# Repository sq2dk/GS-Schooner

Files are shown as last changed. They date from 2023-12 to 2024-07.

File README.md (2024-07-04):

# GS-Schooner
SP2ZIE Schooner Ground Station

This is repository for Ground Station for PWSat-3 satellite.

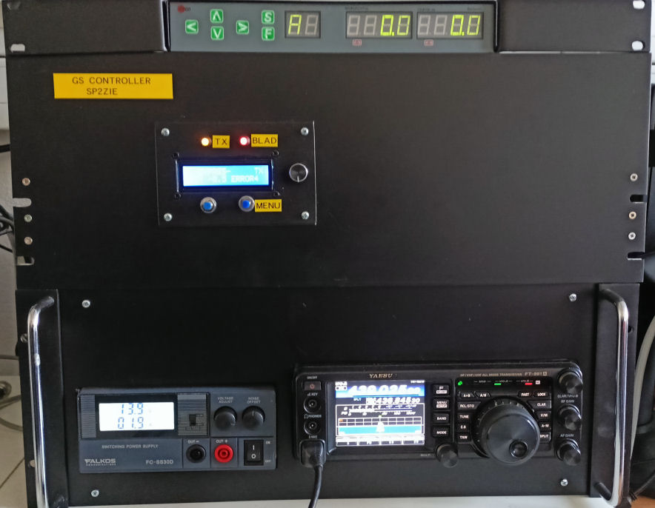
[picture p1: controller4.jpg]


## Overview

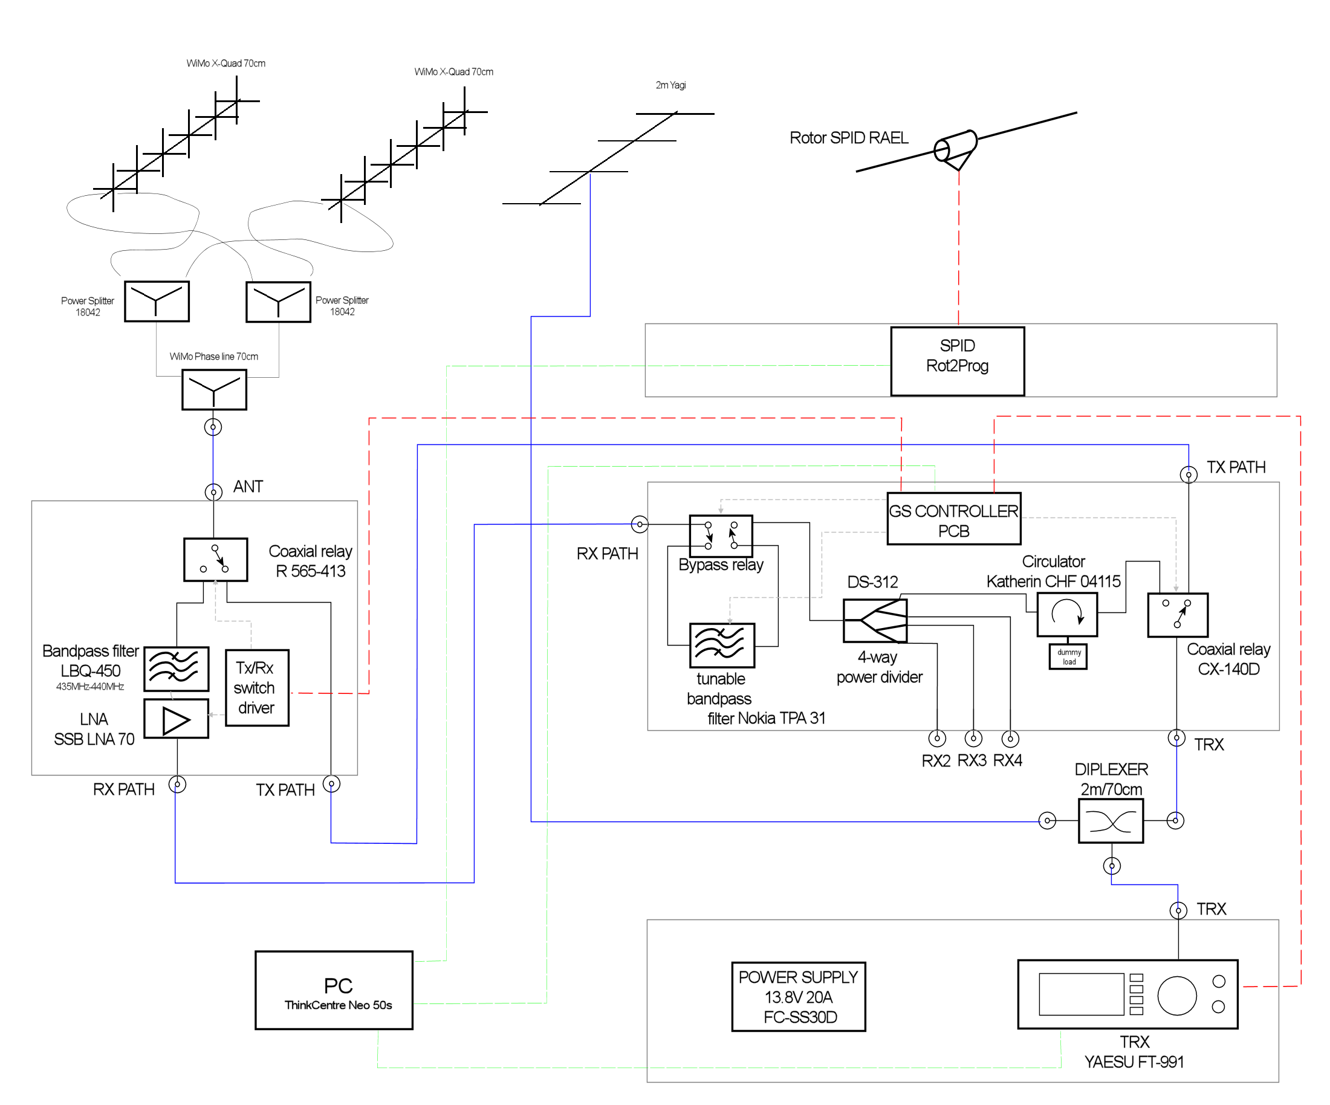
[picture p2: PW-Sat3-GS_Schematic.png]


Future PWSat-3 satellite will have communication module based on simplex operation on 437.xxxMHz. Modulation used would be most likely 2GFSK with downlink speeds from 1200bd up to maximum possible speeds which assure correct decoding. Uplink speeds will be probably limited to max 9600bd. Satellite will be using Endurosat UHF Transceiver II module, which seem to be based on one of the popular sub-gigahertz communications IC such as SI4463 or similar.

Simplex operation means that the same frequency will be used for uplink and transmit. This poses additional challenge of switching between transmitting and receiving, as the same antenna will be used both for transmit and receive side. Additionally to ensure effective communication with satellite, high transmit power should be used, and since satellite itself uses low power transmitter, ground station receiver has to be able to receive low signals. 

To help with weak signal receiving and maximizing power radiating by transmitter directional antennas have to be used. We have decided to use system of two shorter directional antennas rather, than one long antenna, as they are more manageable mechanicaly. Due to the undetermined orientation of satellite in space antennas have to have circular polarisation to avoid signal fade-outs.

Since antennas are directional, they need to be painted to satellite at all times – antenna rotator able to change position in azimuth and elevation is required.

To compensate for coaxial cable loss low noise amplifier for received signals is used placed next to the antenna. 

Due to high radio noise environment and presence of nearby high power transmitters on frequencies lying close to frequency of interest RF bandpass filter is added before LNA, not to saturate amplifier with unwanted signal.

Additional very low passband (about 100kHz) filter can be connected in line to further limit noise from unwanted transmissions. This filter due to low bandpass characteristic is tunable by stepper motor to tune to required frequency.

Received signal is further divided to 4 paths to allow simultaneous operation of up to 4 receivers (main station and up to 3 SDR receivers). Those might be essential to decode transmissions with speed of above 9600bd. 

TX path of the station leads directly from transmitter to antennas via 2 relays.

Yaesu FT-991 wash chosen as main transceiver. Although this radio is not specifically designed for satellite use, transceiver was only one currently in production and available on the market capable of producing 50W of RF power on 70cm band with 9600bd transmission/rx capability. 

## GS controller

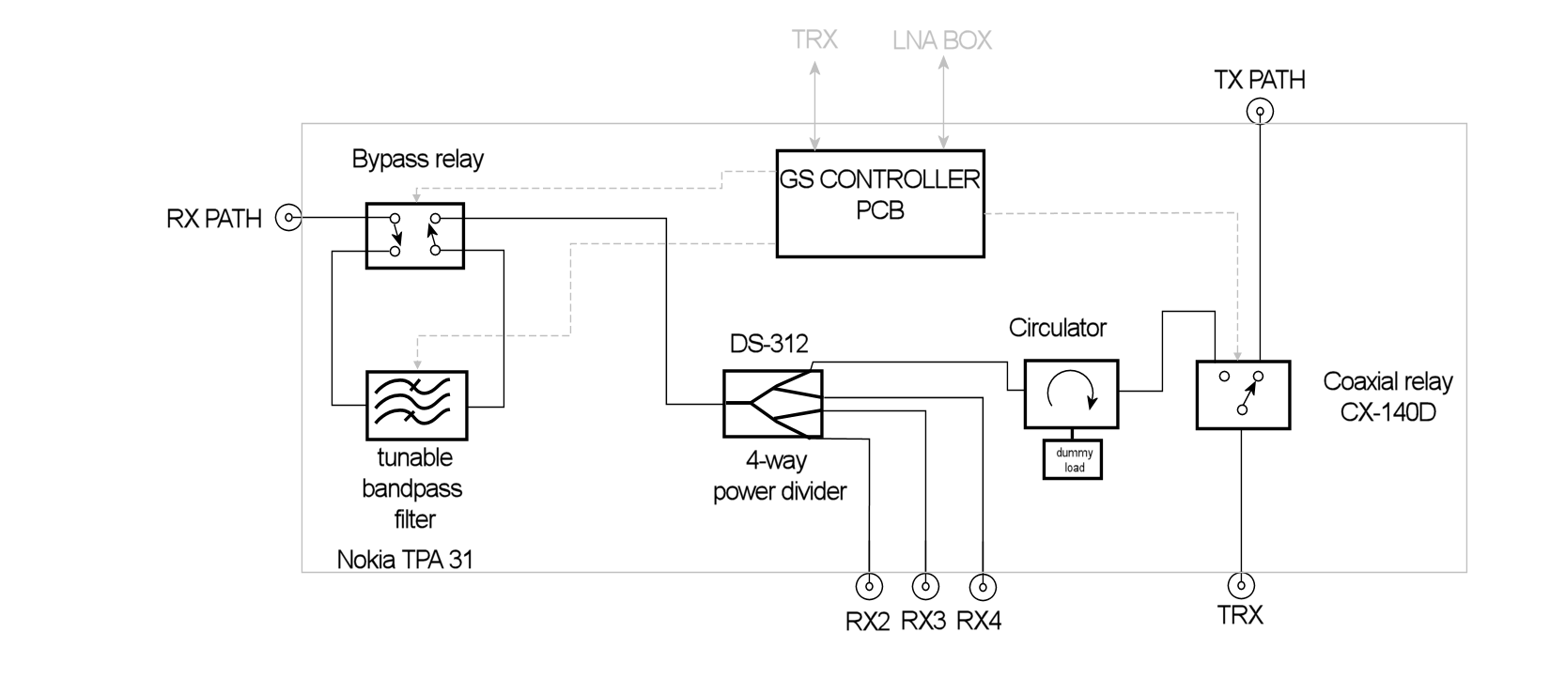
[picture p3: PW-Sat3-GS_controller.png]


Primary role of GS controller is managing switching between transmit and receive modes. Additionally block is additionally filtering and distributing signal for the receivers. All functions can be controlled by computer by serial protocol or manually by keys and encoders. On request from transmitter controller is checking if all conditions for transmit switching are meet and only then sends signal back to TRX to allow transmitting. Control and switching function as well as human interface functions are made by specially designed PCB based on STM blue pill microcontroller. Schematic of electronic circuit and PCB designed can be found in appropriate folder.  
Embedded software is written in Arduino environment and it is available in appropriate folder. 

## LNA Box
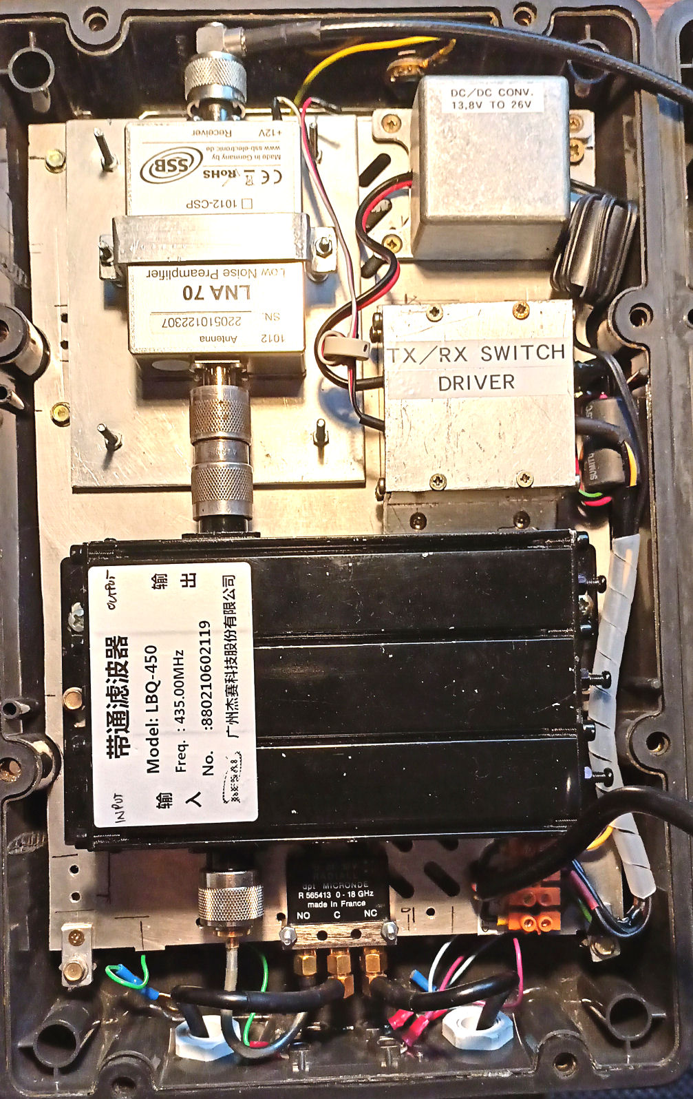
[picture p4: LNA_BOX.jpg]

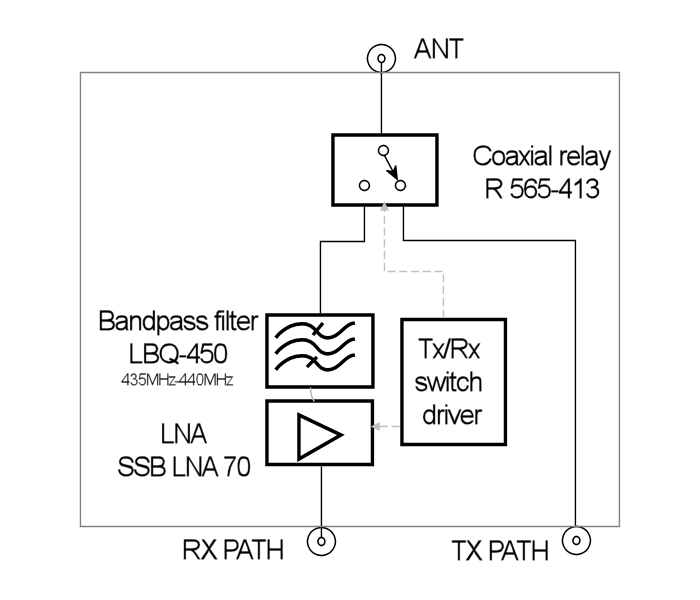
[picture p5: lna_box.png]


This part contains LNA, RF bandpass filter, RF relay and electronic driver for relay and LNA power supply. Schematic and PCB design for driver is included in appropriate folder. This is a simple transistor and relay switch. 4 wire interface to GS controlled is used. 12V power, ground, RX signal (to GND) and feedback signal are passed from/to GS controller. Separate TX and RX lines are feed from GS controller to LNA box. Although this solution requires extra coaxial cable, it simplifies design a bit, since other coaxial relay for TX/RX switching can be placed in below deck equipment (BDE).  
## Antenna system

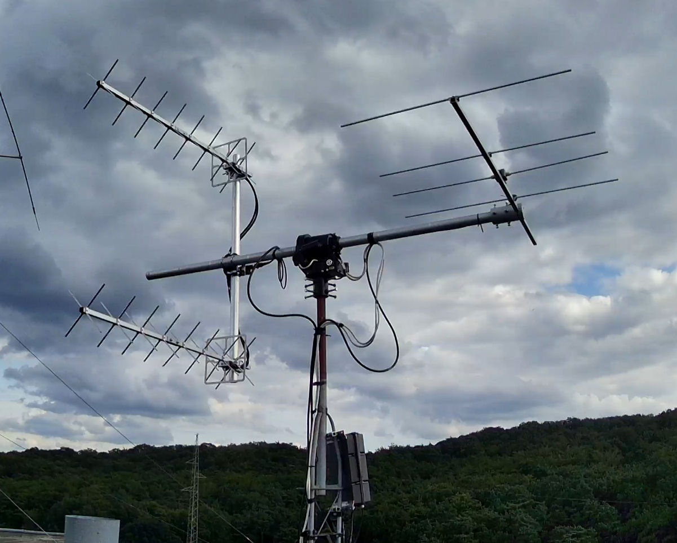
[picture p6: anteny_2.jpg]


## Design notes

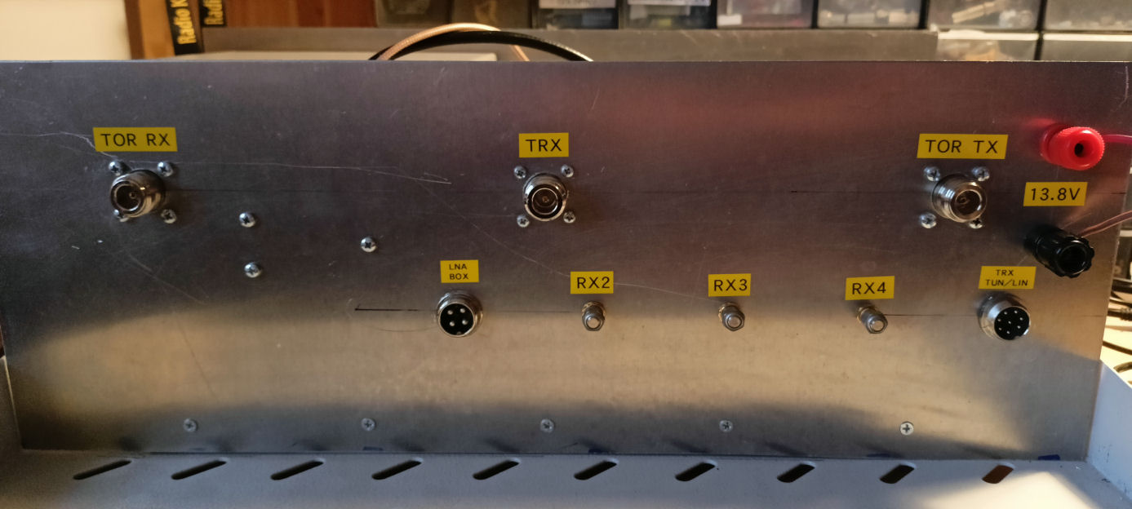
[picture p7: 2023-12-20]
controller1.jpg

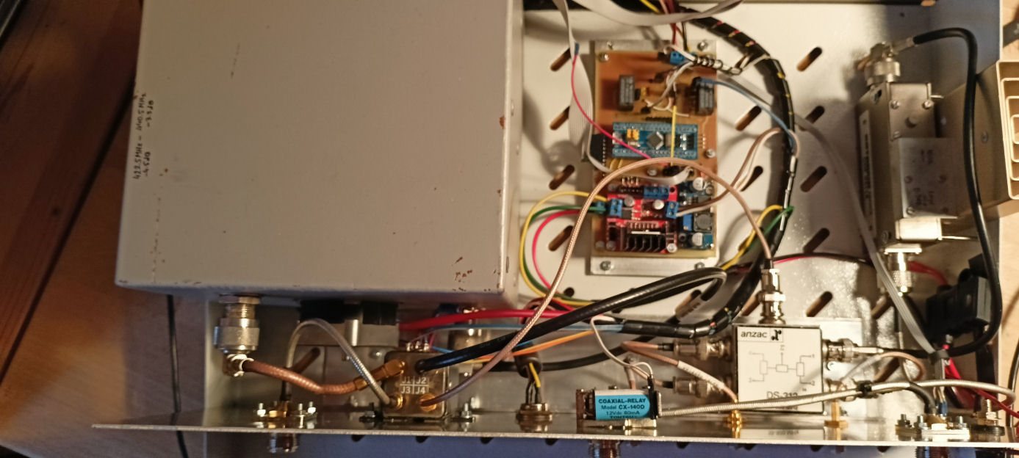
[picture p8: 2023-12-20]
controller2.jpg

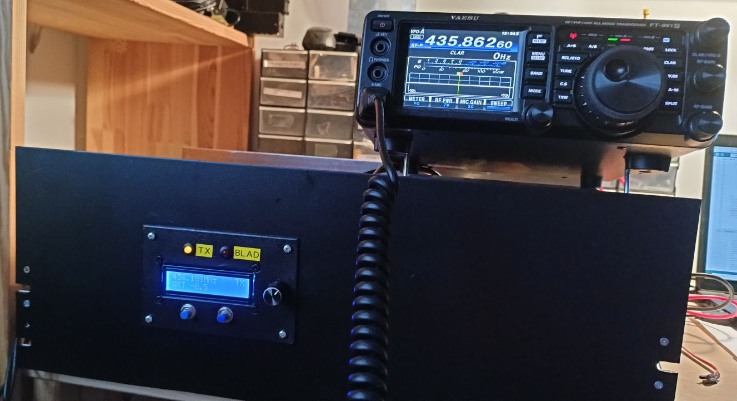
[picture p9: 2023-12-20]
controller3.jpg

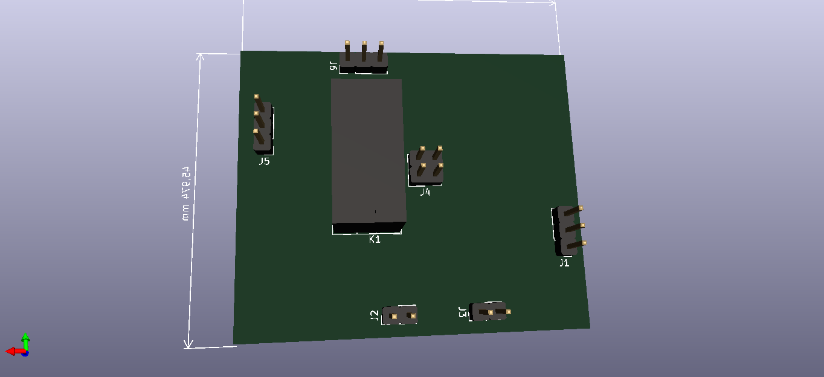
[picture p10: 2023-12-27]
lna_switch/lna_switch_2.png

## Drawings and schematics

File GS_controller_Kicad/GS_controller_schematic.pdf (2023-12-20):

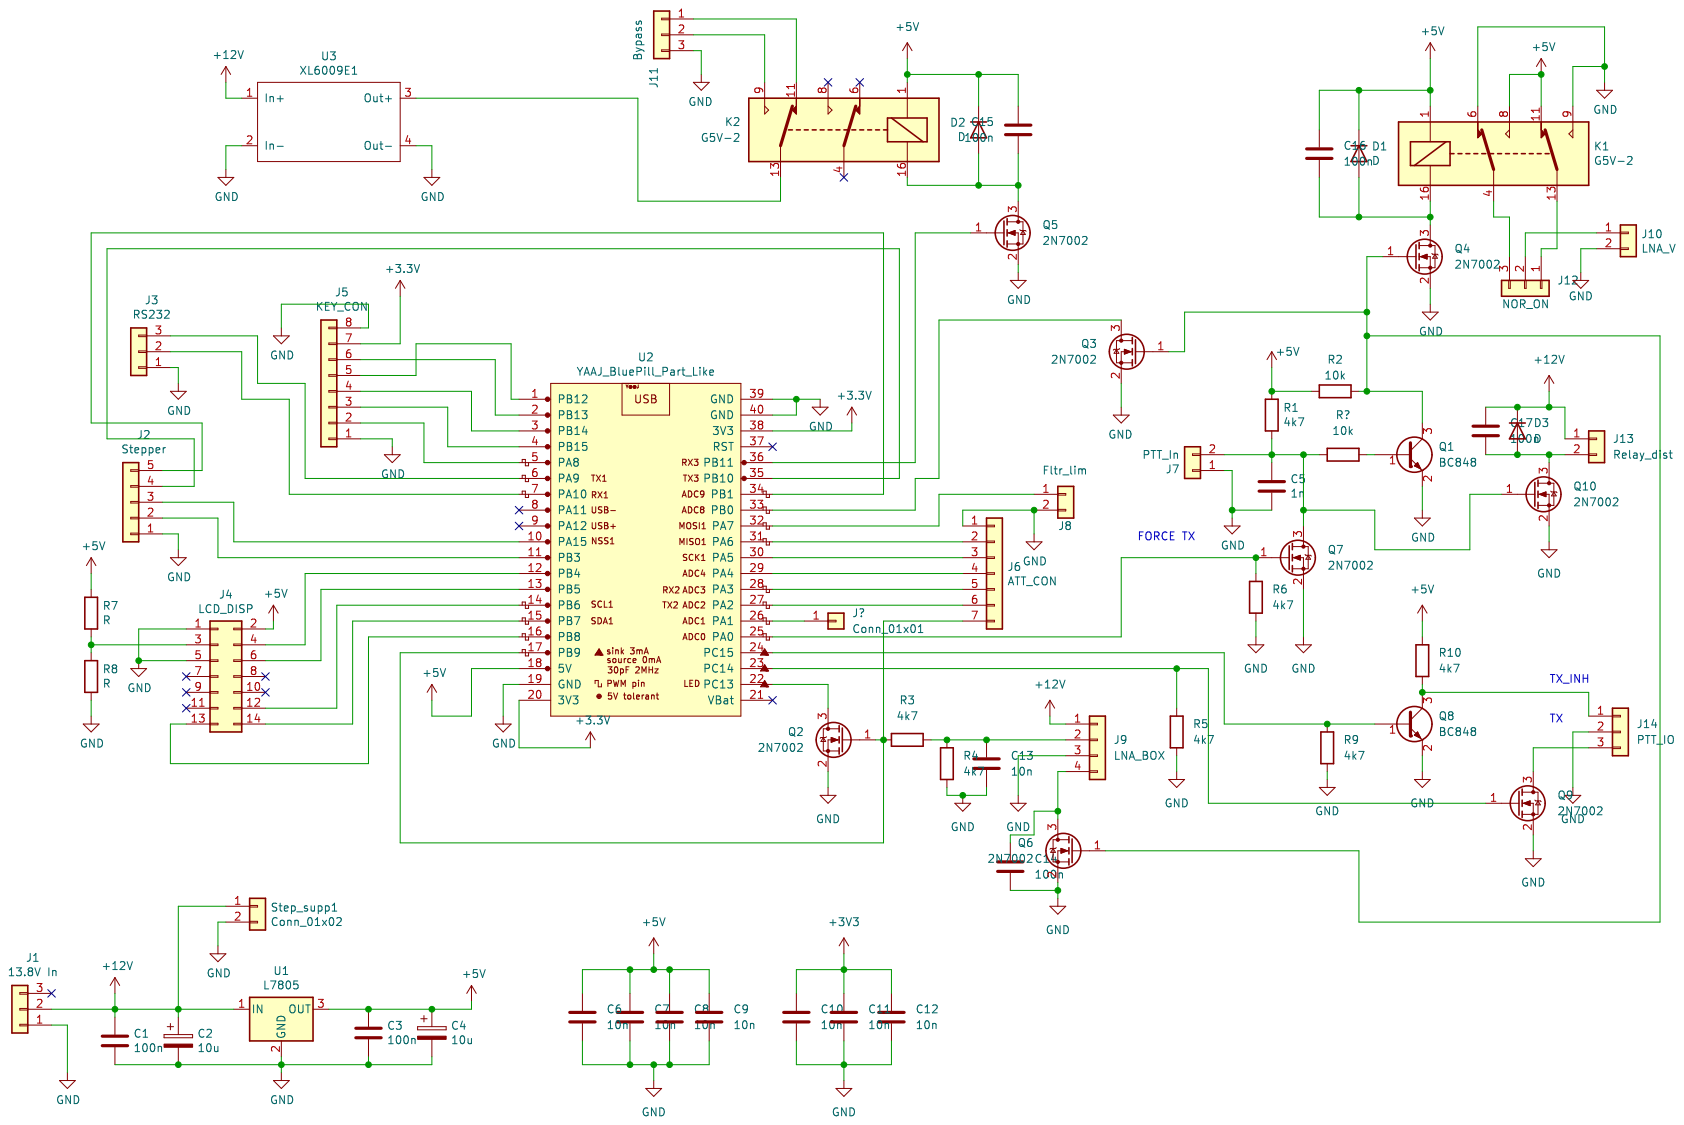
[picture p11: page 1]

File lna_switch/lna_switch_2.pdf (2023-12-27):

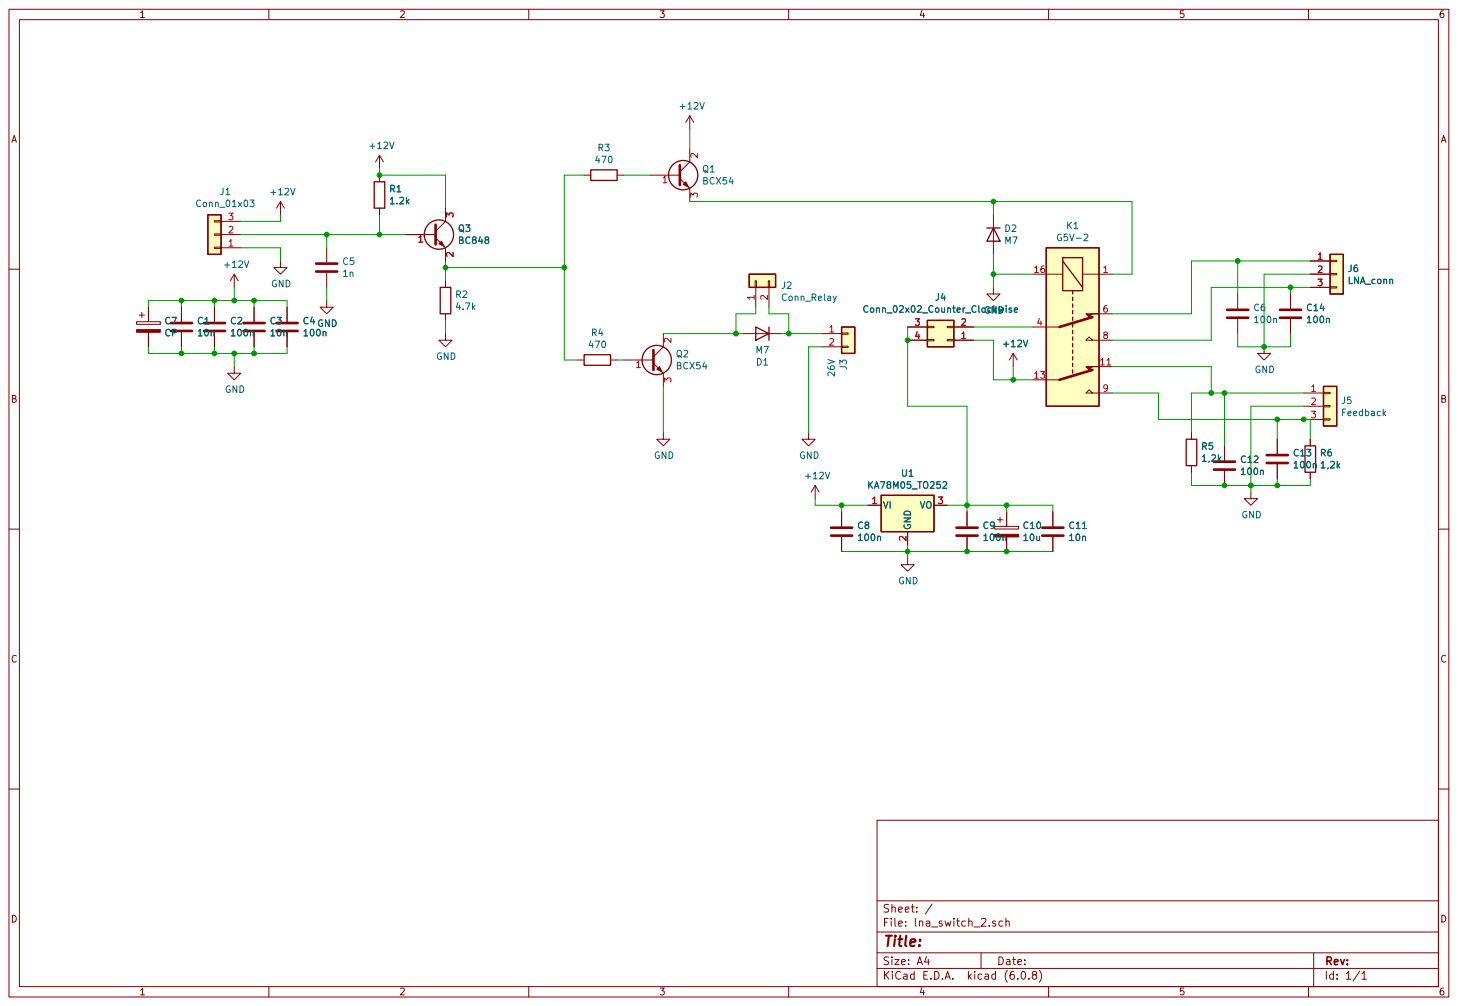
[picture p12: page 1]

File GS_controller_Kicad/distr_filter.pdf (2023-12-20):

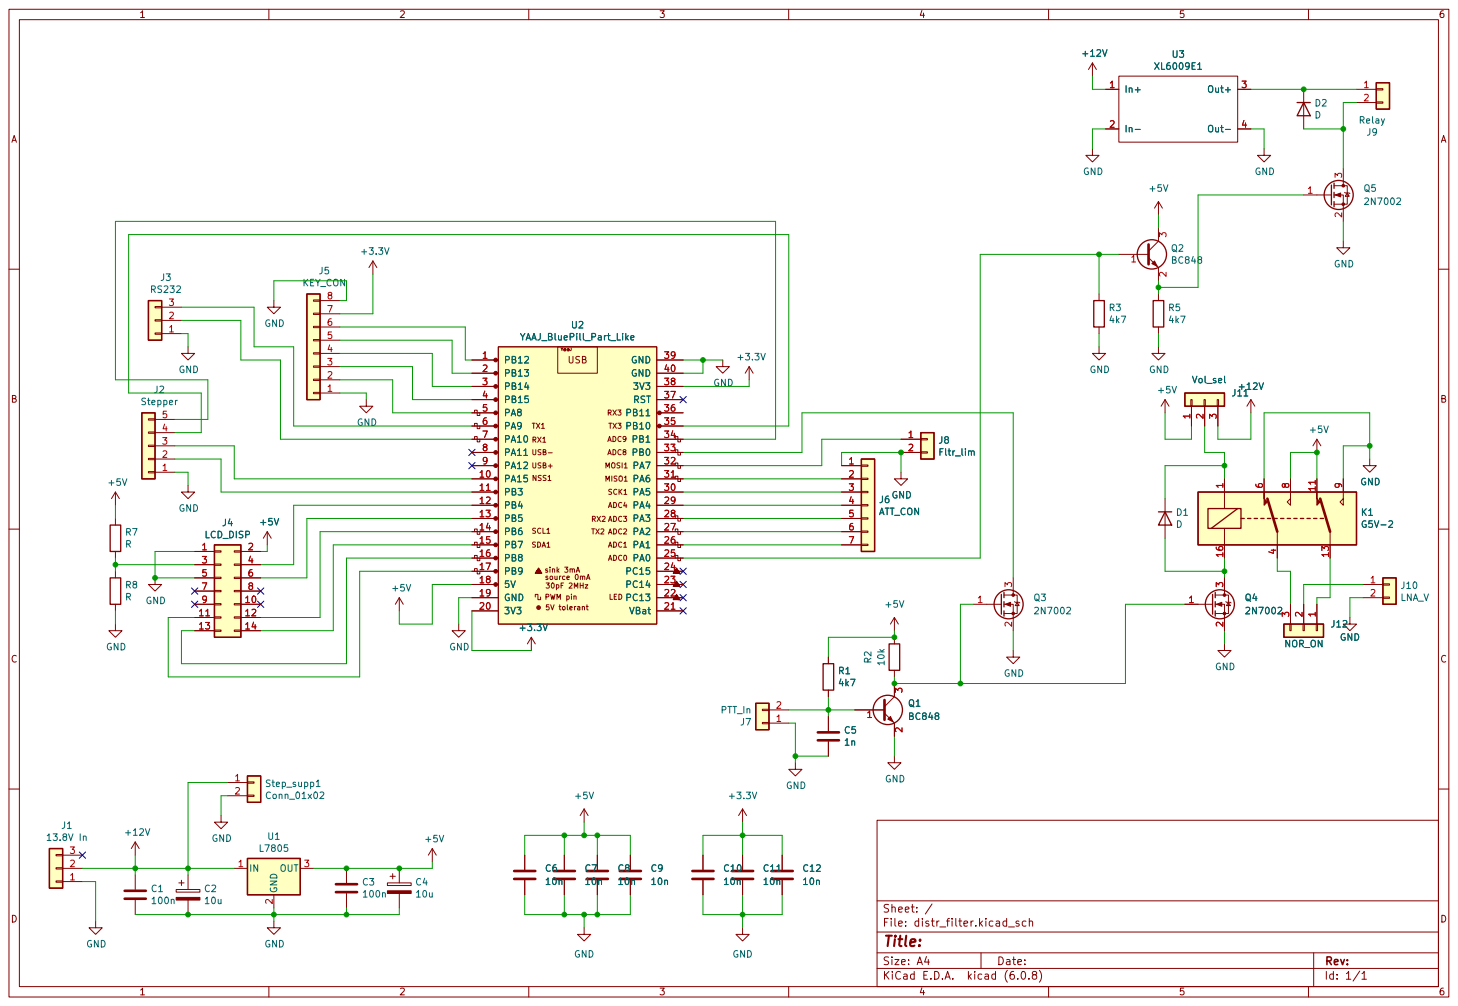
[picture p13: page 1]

3 3 | 4 4
5 5 | 6 6

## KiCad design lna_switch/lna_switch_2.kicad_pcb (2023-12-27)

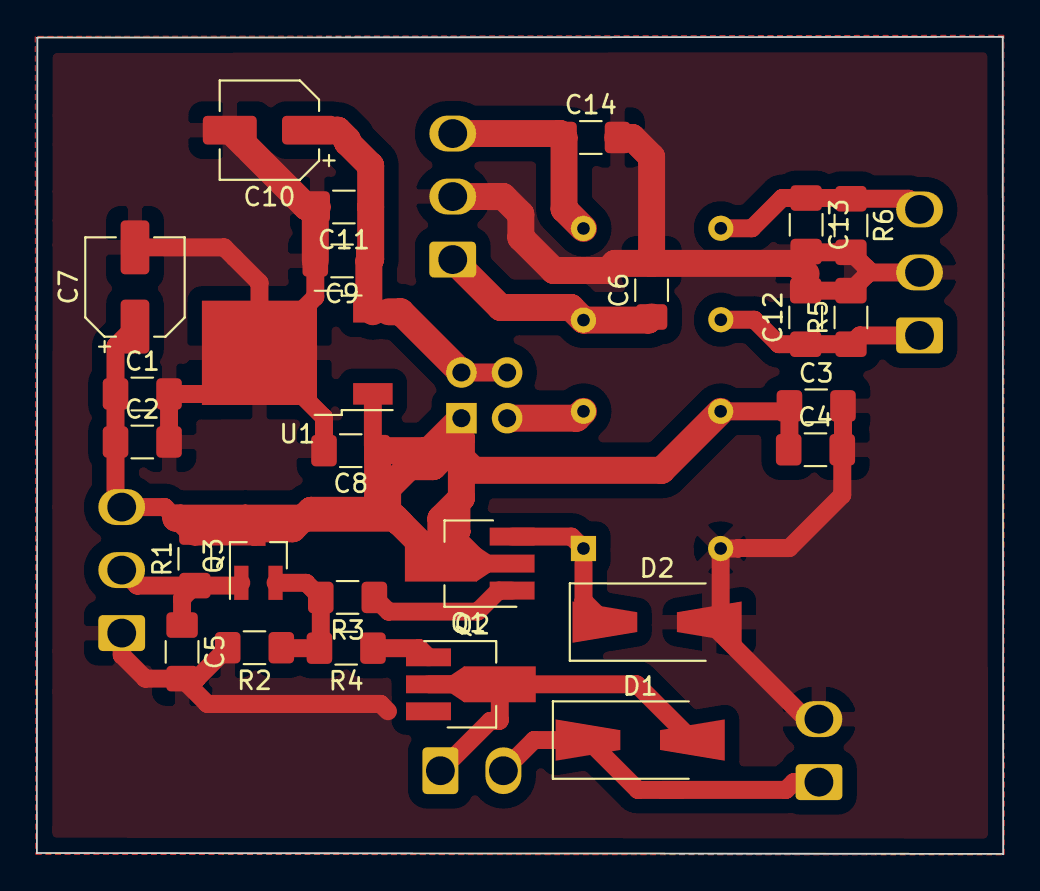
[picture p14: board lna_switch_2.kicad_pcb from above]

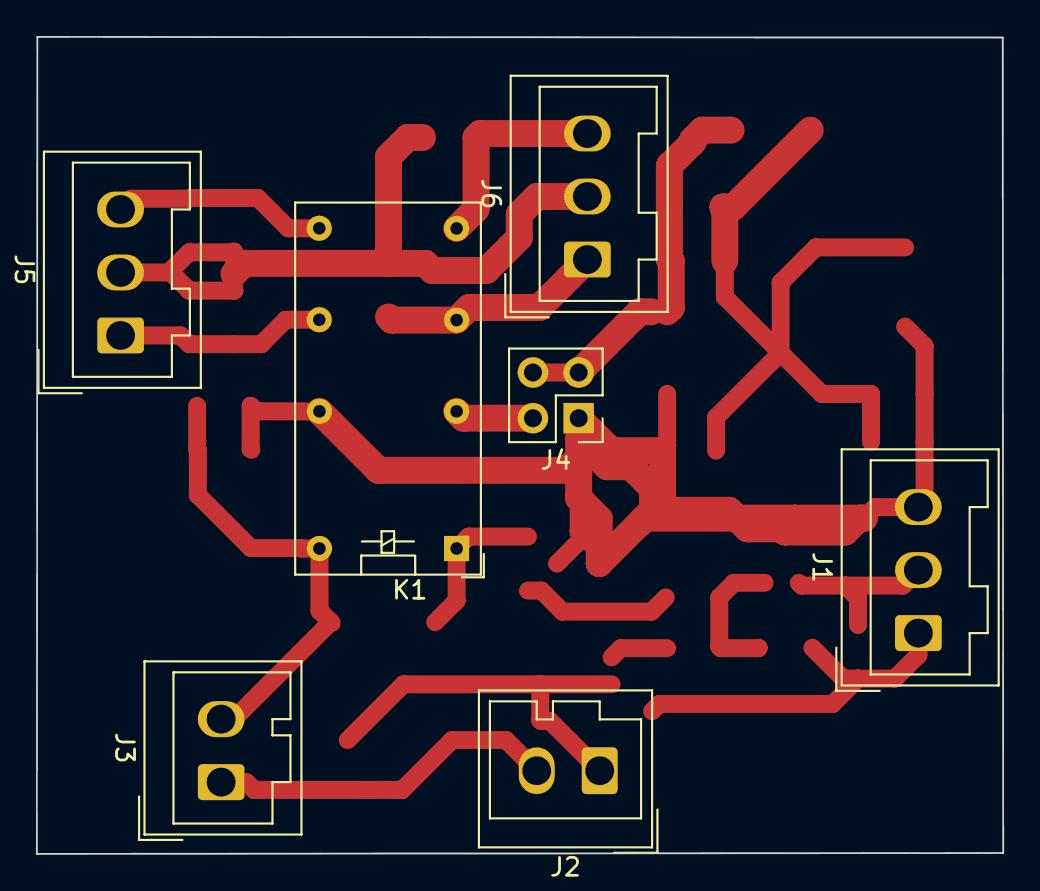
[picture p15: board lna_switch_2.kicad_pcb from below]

Board: 2 copper layers, 53.7 x 45.4 mm, 33 parts (7 on the bottom side), 15 nets.

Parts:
C1, C3, C11: 10n; C_1206_3216Metric_Pad1.42x1.75mm_HandSolder
C2, C4, C6, C8, C9, C12, C13, C14: 100n; C_1206_3216Metric_Pad1.42x1.75mm_HandSolder
C5: 1n; C_1206_3216Metric_Pad1.42x1.75mm_HandSolder
C7: CP; CP_Elec_5x3
C10: 10u; CP_Elec_5x3
D1, D2: M7; D_SMA-SMB_Universal_Handsoldering
J1: Conn_01x03; Wago_734-133_1x03_P3.50mm_Vertical
J2: Conn_Relay; Wago_734-132_1x02_P3.50mm_Vertical
J3: 26V; Wago_734-132_1x02_P3.50mm_Vertical
J4: Conn_02x02_Counter_Clockwise; PinHeader_2x02_P2.54mm_Vertical
J5: Feedback; Wago_734-133_1x03_P3.50mm_Vertical
J6: LNA_conn; Wago_734-133_1x03_P3.50mm_Vertical
K1: G5V-2; Relay_DPDT_Omron_G5V-2
Q1, Q2: BCX54; SOT-89-3_Handsoldering
Q3: BC848; SOT-23_Handsoldering
R1: 1.2k; R_1206_3216Metric_Pad1.42x1.75mm_HandSolder
R2: 4.7k; R_1206_3216Metric_Pad1.42x1.75mm_HandSolder
R3, R4: 470; R_1206_3216Metric_Pad1.42x1.75mm_HandSolder
R5, R6: 1,2k; R_1206_3216Metric_Pad1.42x1.75mm_HandSolder
U1: KA78M05_TO252; TO-252-2

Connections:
+12V: C1.1, C2.1, C3.1, C4.1, C7.1, C8.1, J1.3, J4.1, K1.13, Q1.2, Q3.3, R1.2, U1.1
GND: C1.2, C2.2, C3.2, C4.2, C5.2, C6.2, C7.2, C8.2, C9.2, C10.2, C11.2, C12.2, C13.2, C14.2, D2.2, J1.1, J3.2, J5.2, J6.2, K1.16, R2.2, R5.2, R6.2, U1.2
unnamed: C5.1, J1.2, Q3.1, R1.1
unnamed: C6.1, J6.1, K1.6
unnamed: C9.1, C10.1, C11.1, J4.3, J4.4, U1.3
unnamed: C12.1, J5.1, K1.11, R5.1
unnamed: C13.1, J5.3, K1.9, R6.1
unnamed: C14.1, J6.3, K1.8
unnamed: D1.1, J2.2, J3.1
unnamed: D1.2, J2.1, Q2.2
unnamed: D2.1, K1.1, Q1.3
unnamed: J4.2, K1.4
unnamed: Q1.1, R3.1
unnamed: Q2.1, R4.1
unnamed: Q3.2, R2.1, R3.2, R4.2

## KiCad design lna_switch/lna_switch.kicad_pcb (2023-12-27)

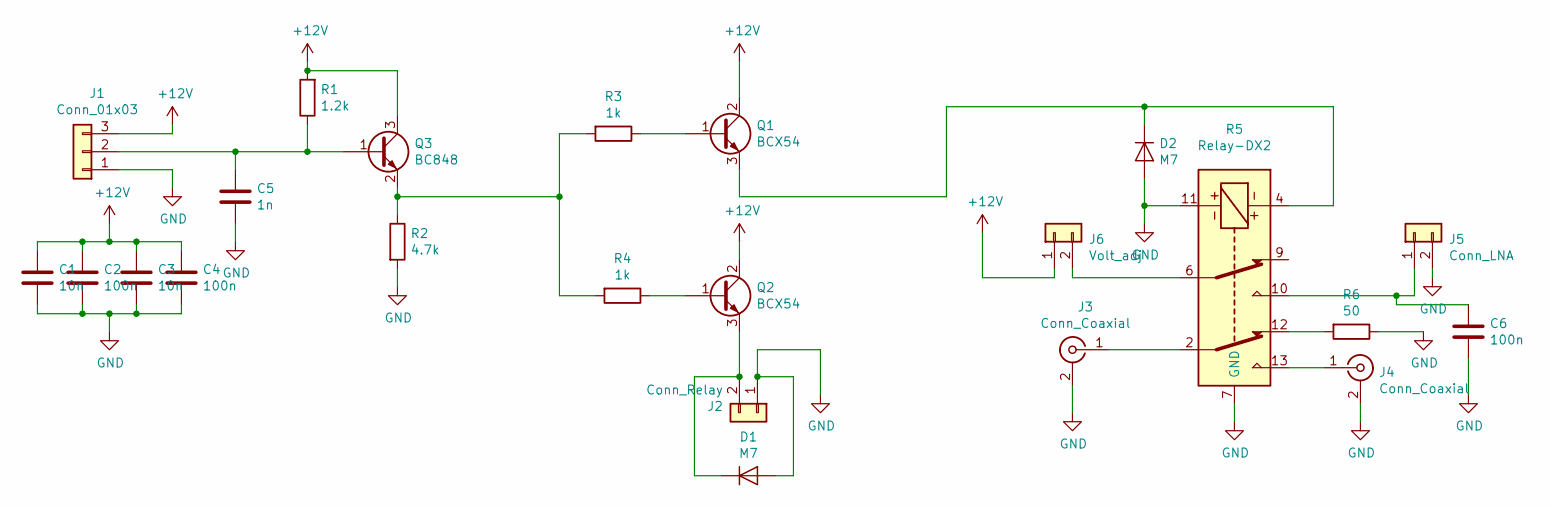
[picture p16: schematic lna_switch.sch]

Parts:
C1, C3: 10n; C_1206_3216Metric_Pad1.42x1.75mm_HandSolder
C2, C4, C6: 100n; C_1206_3216Metric_Pad1.42x1.75mm_HandSolder
C5: 1n; C_1206_3216Metric_Pad1.42x1.75mm_HandSolder
D1, D2: M7; D_SMA-SMB_Universal_Handsoldering
J1: Conn_01x03; PinHeader_1x03_P2.54mm_Vertical
J2: Conn_Relay; PinHeader_1x02_P2.54mm_Vertical
J3, J4: Conn_Coaxial; SMA_Samtec_SMA-J-P-H-ST-EM1_EdgeMount
J5: Conn_LNA; PinHeader_1x02_P2.54mm_Vertical
J6: Volt_adj; PinHeader_1x02_P2.54mm_Vertical
Q1, Q2: BCX54; SOT-89-3_Handsoldering
Q3: BC848; SOT-23_Handsoldering
R1: 1.2k; R_1206_3216Metric_Pad1.42x1.75mm_HandSolder
R2: 4.7k; R_1206_3216Metric_Pad1.42x1.75mm_HandSolder
R3, R4: 1k; R_1206_3216Metric_Pad1.42x1.75mm_HandSolder
R5: Relay-DX2; DIP-14_W7.62mm_LongPads
R6: 50; R_1206_3216Metric_Pad1.42x1.75mm_HandSolder

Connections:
+12V: C1.1, C2.1, C3.1, C4.1, J1.3, J6.1, Q1.2 (C), Q2.2 (C), Q3.3 (C), R1.2
GND: C1.2, C2.2, C3.2, C4.2, C5.2, C6.2, D1.2 (A), D2.2 (A), J1.1, J2.1, J3.2 (Ext), J4.2 (Ext), J5.2, R2.2, R5.7 (GND), R5.11, R6.1
unnamed: C5.1, J1.2, Q3.1 (B), R1.1
unnamed: C6.1, J5.1, R5.10
unnamed: D1.1 (K), J2.2, Q2.3 (E)
unnamed: D2.1 (K), Q1.3 (E), R5.4
unnamed: J3.1 (In), R5.2
unnamed: J4.1 (In), R5.13
unnamed: J6.2, R5.6
unnamed: Q1.1 (B), R3.1
unnamed: Q2.1 (B), R4.1
unnamed: Q3.2 (E), R2.1, R3.2, R4.2
unnamed: R5.1, R5.3, R5.5, R5.8, R5.14
unnamed: R5.12, R6.2

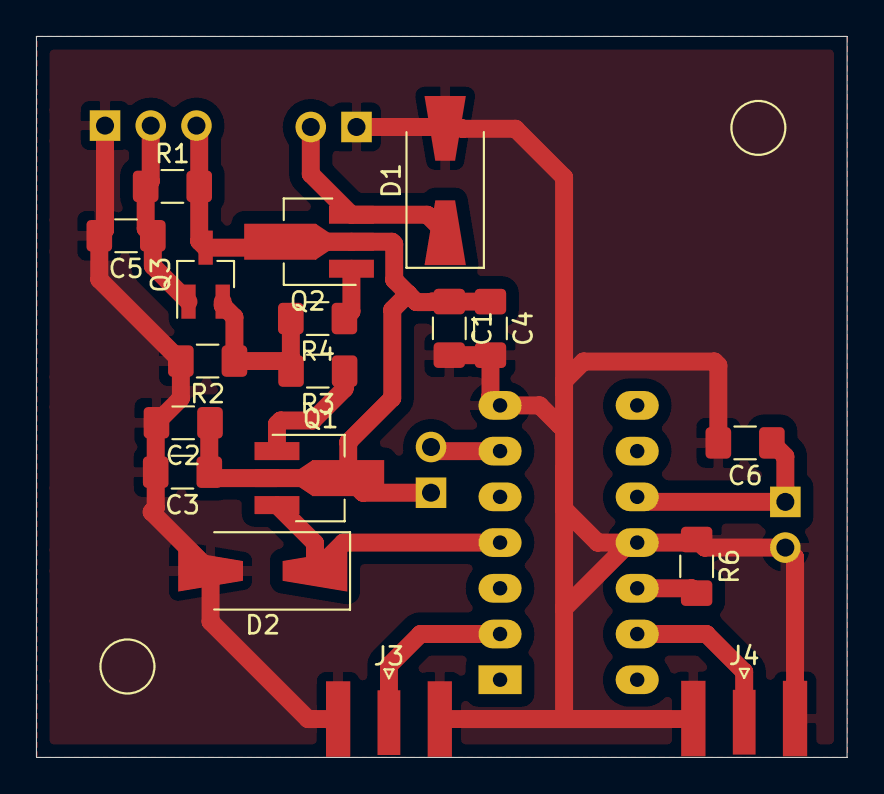
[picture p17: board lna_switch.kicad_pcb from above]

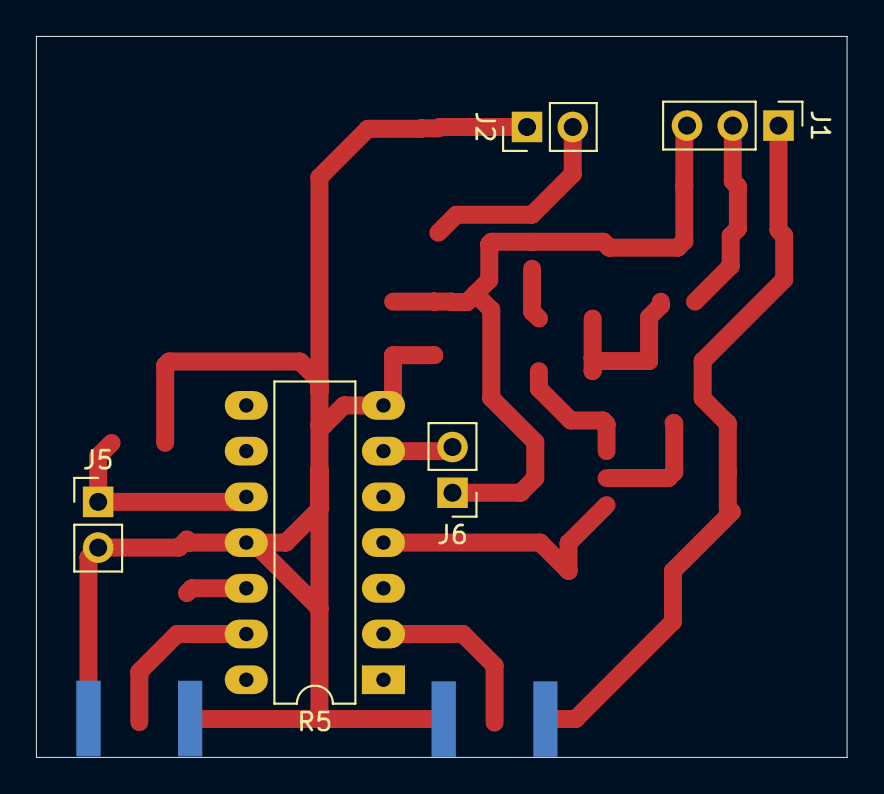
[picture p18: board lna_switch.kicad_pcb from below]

Board: 2 copper layers, 45.0 x 40.1 mm, 23 parts (5 on the bottom side), 14 nets.

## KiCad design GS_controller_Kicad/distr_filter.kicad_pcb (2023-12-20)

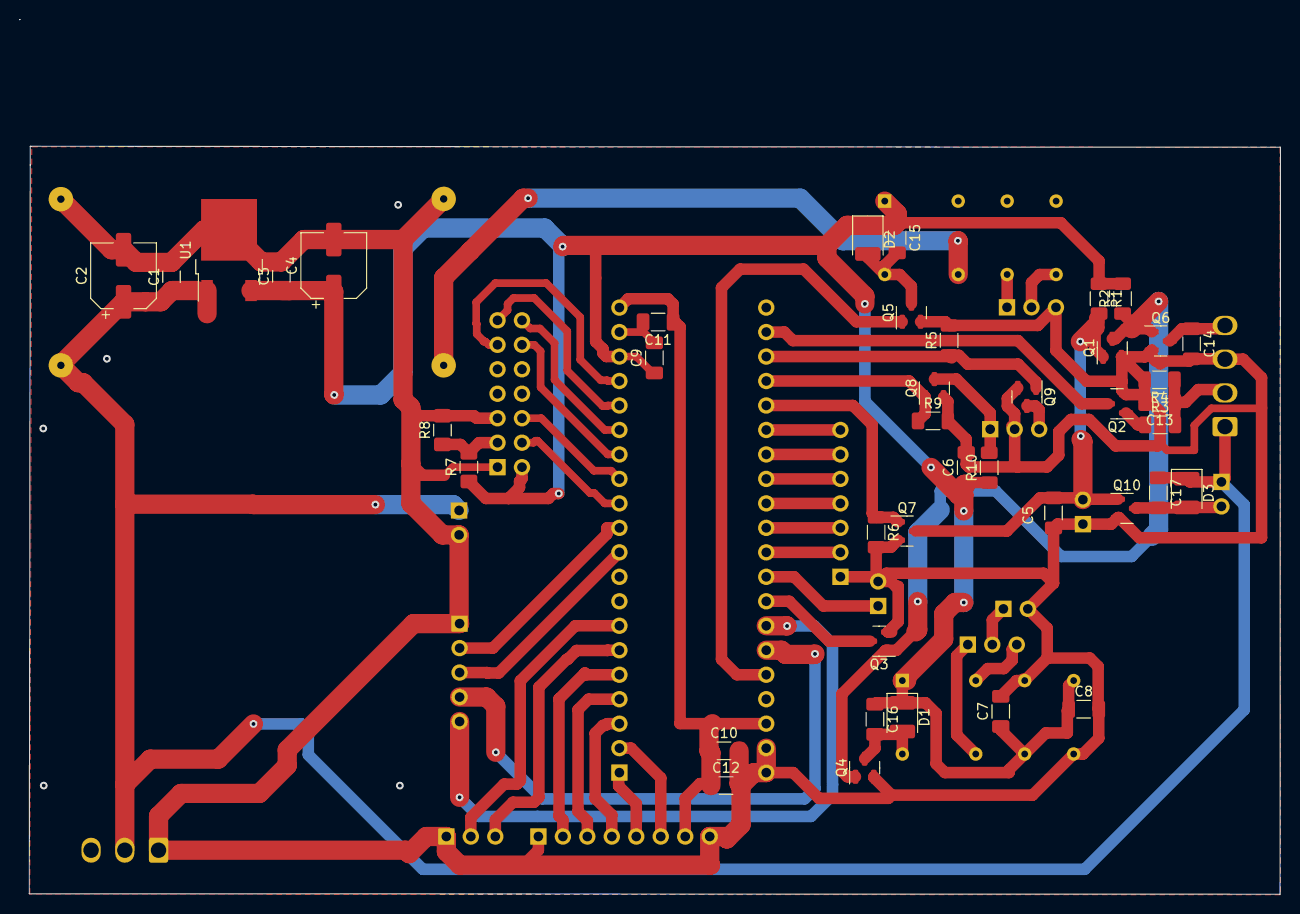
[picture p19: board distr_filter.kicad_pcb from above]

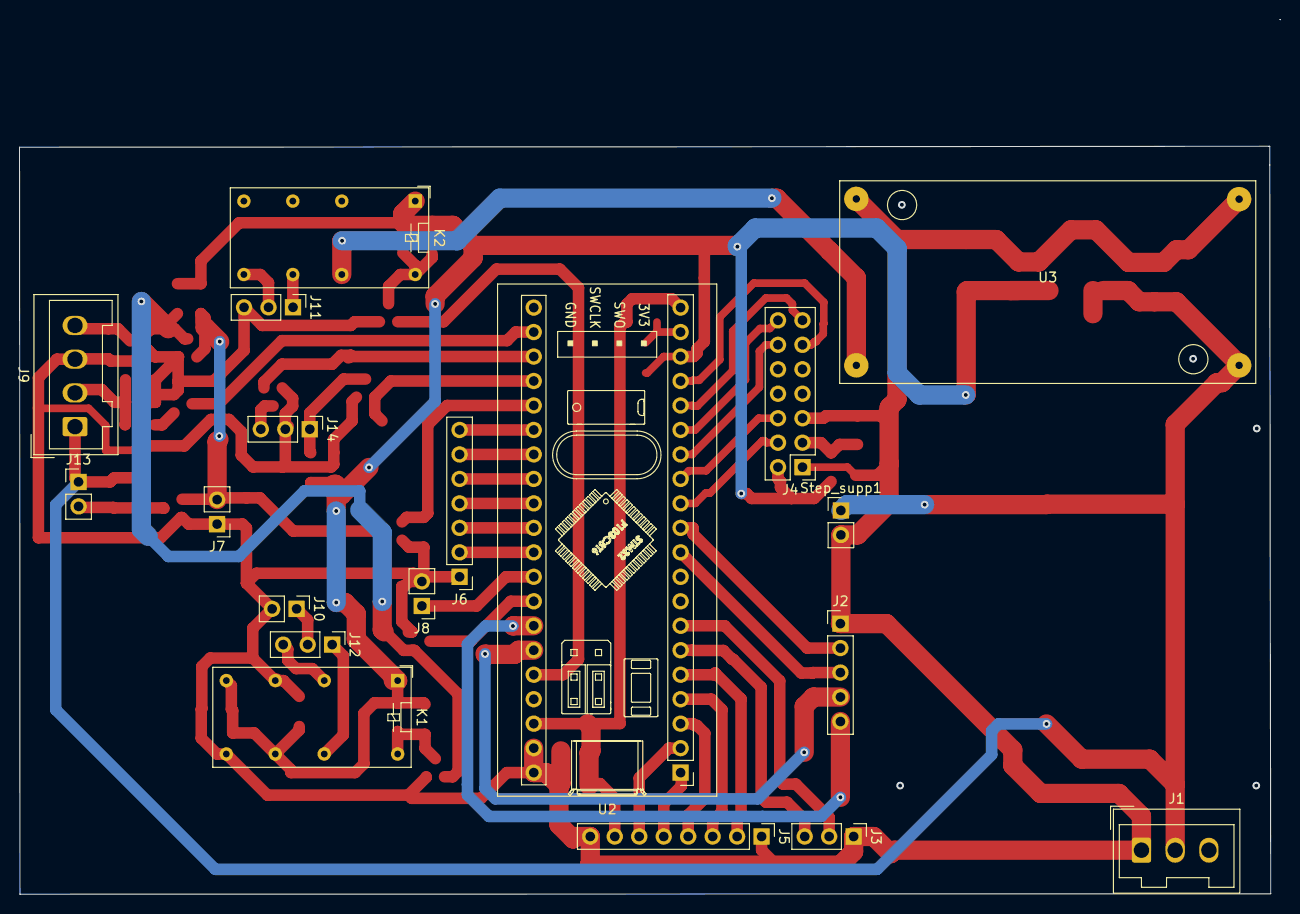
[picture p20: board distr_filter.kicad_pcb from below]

Board: 2 copper layers, 129.8 x 77.6 mm, 60 parts (19 on the bottom side), 51 nets.

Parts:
C1, C3: 100n; C_1206_3216Metric_Pad1.42x1.75mm_HandSolder
C2, C4: 10u; CP_Elec_6.3x5.7
C5: 1n; C_1206_3216Metric_Pad1.33x1.80mm_HandSolder
C6, C7, C8, C9, C10, C11, C12, C13: 10n; C_1206_3216Metric_Pad1.33x1.80mm_HandSolder
C14, C15, C16, C17: 100n; C_1206_3216Metric_Pad1.33x1.80mm_HandSolder
D1, D2, D3: D; D_1210_3225Metric_Pad1.42x2.65mm_HandSolder
J1: 13.8V In; Wago_734-133_1x03_P3.50mm_Vertical
J2: Stepper; PinHeader_1x05_P2.54mm_Vertical
J3: RS232; PinHeader_1x03_P2.54mm_Vertical
J4: LCD_DISP; PinHeader_2x07_P2.54mm_Vertical
J5: KEY_CON; PinHeader_1x08_P2.54mm_Vertical
J6: ATT_CON; PinHeader_1x07_P2.54mm_Vertical
J7: PTT_In; PinHeader_1x02_P2.54mm_Vertical
J8: Fltr_lim; PinHeader_1x02_P2.54mm_Vertical
J9: LNA_BOX; Wago_734-134_1x04_P3.50mm_Vertical
J10: LNA_V; PinHeader_1x02_P2.54mm_Vertical
J11: Bypass; PinHeader_1x03_P2.54mm_Vertical
J12: NOR_ON; PinHeader_1x03_P2.54mm_Vertical
J13: Relay_dist; PinHeader_1x02_P2.54mm_Vertical
J14: PTT_IO; PinHeader_1x03_P2.54mm_Vertical
K1, K2: G5V-2; Relay_DPDT_Omron_G5V-2
Q1, Q8: BC848; SOT-23
Q2, Q3, Q4, Q5, Q6, Q7, Q9, Q10: 2N7002; SOT-23
R1, R3, R4, R5, R6, R9, R10: 4k7; R_1206_3216Metric_Pad1.30x1.75mm_HandSolder
R2: 10k; R_1206_3216Metric_Pad1.30x1.75mm_HandSolder
R7, R8: R; R_1206_3216Metric_Pad1.42x1.75mm_HandSolder
Step_supp1: Conn_01x02; PinHeader_1x02_P2.54mm_Vertical
U1: L7805; TO-252-2
U2: YAAJ_BluePill_Part_Like; YAAJ_BluePill_1
U3: XL6009E1; XL6009E

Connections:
+3V3: C10.1, C11.1, C12.1, J5.7, U2.20 (3V3), U2.38 (3V3)
+5V: C3.1, C4.1, C6.1, C7.1, C8.1, C9.1, C15.1, C16.1, D1.1 (K), D2.1 (K), J4.2, K1.1, K1.8, K1.11, K2.1, R1.1, R2.2, R7.1, R10.1, U1.3 (OUT), U2.18 (5V)
+12V: C1.1, C2.1, C17.1, D3.1 (K), J1.2, J9.1, J13.1, Step_supp1.1, U1.1 (IN), U3.1 (In+)
GND: C1.2, C2.2, C3.2, C4.2, C5.2, C6.2, C7.2, C8.2, C9.2, C10.2, C11.2, C12.2, C13.2, C14.2, J1.1, J2.1, J3.1, J4.1, J4.5, J5.1, J5.8, J6.1, J7.1, J8.2, J9.3, J10.2, J11.3, J14.2, K1.6, K1.9, Q1.2 (E), Q2.2 (S), Q3.2 (S), Q4.2 (S), Q5.2 (S), Q6.2 (S), Q7.2 (S), Q8.2 (E), Q9.2 (S), Q10.2 (S), R4.2, R5.2, R6.2, R8.2, R9.2, Step_supp1.2, U1.2 (GND), U2.19 (GND), U2.39 (GND), U2.40 (GND), U3.2 (In-), U3.4 (Out-)
unnamed: C5.1, J7.2, Q1.1 (B), Q7.3 (D), Q10.1 (G), R1.2
unnamed: C13.1, J9.2, R3.2, R4.1
unnamed: C14.1, J9.4, Q6.3 (D)
unnamed: C15.2, D2.2 (A), K2.16, Q5.3 (D)
unnamed: C16.2, D1.2 (A), K1.16, Q4.3 (D)
unnamed: C17.2, D3.2 (A), J13.2, Q10.3 (D)
unnamed: J2.2, U2.11 (PB3)
unnamed: J2.3, U2.10 (PA15)
unnamed: J2.4, U2.35 (PB10)
unnamed: J2.5, U2.34 (PB1)
unnamed: J3.2, U2.7 (PA10)
unnamed: J3.3, U2.6 (PA9)
unnamed: J4.3, R7.2, R8.1
unnamed: J4.4, U2.12 (PB4)
unnamed: J4.6, U2.13 (PB5)
unnamed: J4.11, U2.17 (PB9)
unnamed: J4.12, U2.14 (PB6)
unnamed: J4.13, U2.16 (PB8)
unnamed: J4.14, U2.15 (PB7)
unnamed: J5.2, U2.5 (PA8)
unnamed: J5.3, U2.4 (PB15)
unnamed: J5.4, U2.3 (PB14)
unnamed: J5.5, U2.1 (PB12)
unnamed: J5.6, U2.2 (PB13)
unnamed: J6.2, U2.31 (PA6)
unnamed: J6.3, U2.30 (PA5)
unnamed: J6.4, U2.29 (PA4)
unnamed: J6.5, U2.28 (PA3)
unnamed: J6.6, U2.27 (PA2)
unnamed: J6.7, U2.26 (PA1)
unnamed: J8.1, U2.32 (PA7)
unnamed: J10.1, J12.2
unnamed: J11.1, K2.11
unnamed: J11.2, K2.9
unnamed: J12.1, K1.13
unnamed: J12.3, K1.4
unnamed: J14.1, Q8.3 (C), R10.2
unnamed: K2.13, U3.3 (Out+)
unnamed: Q1.3 (C), Q3.1 (G), Q4.1 (G), Q6.1 (G), R2.1
unnamed: Q2.1 (G), R3.1
unnamed: Q2.3 (D), U2.22 (PC13)
unnamed: Q3.3 (D), U2.33 (PB0)
unnamed: Q5.1 (G), U2.36 (PB11)
unnamed: Q7.1 (G), R6.1, U2.25 (PA0)
unnamed: Q8.1 (B), R9.1, U2.24 (PC15)
unnamed: J14.3, Q9.3 (D)
unnamed: Q9.1 (G), R5.1, U2.23 (PC14)

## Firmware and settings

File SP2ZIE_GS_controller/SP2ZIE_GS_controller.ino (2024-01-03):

//This simple program is for driving filter/LNA/distributor made for SP2ZIE PWSat-3 Ground Station

#include <Stepper.h>       // for stepper motor in filter
#include <Wire.h>
#include <LiquidCrystal_I2C.h>
// #include <LiquidCrystal_I2C.h>   //although it is not for STM32 it works.
#include <IWatchdog.h>               //watchdog 

LiquidCrystal_I2C lcd(0x27, 16, 2);


// pinout for STM32 blue pill
#include "config.h"

#define STM32DUINO_CORE


const int stepsPerRevolution = 200;  // change this to fit the number of steps per revolution
const long menu_timeout_max= 3000; //[ms] menu display time



// initialize the stepper library on pins 8 through 11:
Stepper myStepper(stepsPerRevolution, motor_pin_A, motor_pin_B, motor_pin_C, motor_pin_D);
long stepCount = 0;         // number of steps the motor has taken
byte steps_per_MHz = 93;    // number of steps per MHz of cf band change
long initial_qrg = 440870;  // freqiency in kHz (frequency after reset / on limit switch)
long global_qrg;            // current frq;
byte global_att = 1;        // global_var atteunation;
byte bypass_on = 1;         // bypass status 1=on, 0=off  (turn on with bypass actiated)
byte tx_on = 0;             // tx status 1=on, 0=off;
String comm;
int letter=0;
char sign_l;
int step_inc;
int step_inc1;
String step_l;
String NMEA_String;         //for received and transmit data - not more than 82 characters
byte RX_enable=0;           // enable for receiver - if cable not connected RX path not to be enabled.
byte filter_ok=1;           // status of filter 1=OK, 0=ERROR
byte err_code=0;            // error code - 0=no error - bit coded
byte enc_changed=0;         // encoder or keyboard position change indicator
byte kbd_enable=1;          // is keyboard enabled
byte TX_mode=0;
long menu_timeout=menu_timeout_max;     // display menu timout [ms]
byte menu_item=0;           // actie menu item
byte debug_level=1;         // debug level 1=only essential feedback

volatile uint32_t encoderCount;


void setup() {
  //configure attenuator setting pins as output. 
  pinMode(ATT_V1, OUTPUT);
  pinMode(ATT_V2, OUTPUT);
  pinMode(ATT_V3, OUTPUT);
  pinMode(ATT_V4, OUTPUT);
  pinMode(ATT_V5, OUTPUT);
  pinMode(ATT_V6, OUTPUT);

  pinMode(PTT_FORCE,OUTPUT);
  digitalWrite(PTT_FORCE,LOW);

  pinMode(LED_R, OUTPUT);
  digitalWrite(LED_R,LOW);

  pinMode(LED_Y, OUTPUT);
  digitalWrite(LED_Y,LOW);

  pinMode(KEY_L, INPUT_PULLUP);
  pinMode(KEY_R, INPUT_PULLUP);
  pinMode(ENC_PRESS, INPUT_PULLUP);
  pinMode(ENC_CLK, INPUT_PULLUP);
  pinMode(ENC_DATA, INPUT_PULLUP);

  pinMode(CABLE_CONNECTED, INPUT_PULLDOWN);    // pin detecting if cable for radio is connected (connected wen high)
  attachInterrupt(digitalPinToInterrupt(CABLE_CONNECTED), Cable_interrupt, CHANGE);

  pinMode(PTT_INH, OUTPUT);
  digitalWrite(PTT_INH,LOW);

  pinMode(LNABOX_FEEDBACK, INPUT_PULLUP);   //feedback from LNA BOX - Active low

  pinMode(filter_limit_pin, INPUT_PULLUP);  // limit switch active will be shortened to GND.
 
  pinMode(PTT_IN, INPUT_PULLUP);                   // PTT_IN - normally high, active when low.
  
  attachInterrupt(digitalPinToInterrupt(PTT_IN), PTT_interrupt, CHANGE);  //any change on PTT_In to trigger interrupt routine 

  attachInterrupt(digitalPinToInterrupt(KEY_R), menuDisplay, LOW);
  attachInterrupt(digitalPinToInterrupt(KEY_L), menuExe, LOW);

  
  
  pinMode(FLTR_BPS, OUTPUT);                // Pin stiching baypass realy. LOW-signal going through filter, HIGH-filter bypass
  
  keyb_enable();
  
  // initialize the serial port:
  Serial1.begin(9600);             //Serial1 is one connected to right pins, 9600 - slow, but steady
  //lcd.begin(16, 2);                //LCD type decl
  lcd.init();
  lcd.backlight();
  //lcd.setCursor(0, 0); 
  //lcd.print("PW-Sat3");           //Welcome message
  reset_holding();                //just in case reset stepper
  disp_att(global_att);

  digitalWrite(FLTR_BPS,HIGH);
  Cable_interrupt();
 
  if (filter_ok){
     if (debug_level>1) Serial1.println("Reset to zero");
     reset_step();
  }

  bypass_filter(1);       //enable filter bypass

IWatchdog.begin(500000);    //watchdog set to approx 500ms

}


void keyb_enable(){
 #ifdef LIBMAPLE_CORE  
  systick_attach_callback(&encoder1_read);
  //interrupts();
  kbd_enable=1;
  #endif  
 }
  

void keyb_disable(){
   #ifdef LIBMAPLE_CORE  
  systick_attach_callback();
  //noInterrupts();
  kbd_enable=0;
  #endif  
 
  }

void encoder1_read(void)
{
  volatile static uint8_t ABs = 0;
  uint8_t increment=1;
  //step_inc=0;
  if (menu_item!=0) menu_timeout--;
  ABs = (ABs << 2) & 0x0f; //left 2 bits now contain the previous AB key read-out;
  if (digitalRead(ENC_PRESS)==0) increment=10; else increment=1;
  ABs |= (digitalRead(ENC_CLK) << 1) | digitalRead(ENC_DATA);
  
  switch (ABs)
  {
    case 0x0d:
      if (digitalRead(KEY_L)==LOW){              //if with encoder moement we have left key pressed
        global_att++;
        if (global_att>127) {global_att=127;}
        if (debug_level>1) Serial1.println(global_att);

      }
      else {
        step_inc=increment;
      }
      break;
    case 0x0e:
      if (digitalRead(KEY_L)==LOW){              //if with encoder moement we have left key pressed
        if (global_att==1) {global_att=2;}
        global_att--;
        if (debug_level>1) Serial1.println(global_att);
        
      }
      else {
        step_inc=(-1)*increment;
      }
      break;
  }

  
}

void PTT_interrupt() {
long timer_start;
long time_elapsed=0;

timer_start=millis();

  if (digitalRead(PTT_IN)==LOW) {      //if in transmit mode
     set_att(63);                      //max attenaution
     err_code=(err_code & B11111011);         // reesets code for this procedure
     lcd.setCursor(14, 0);
     lcd.print("TX");
     digitalWrite(LED_Y,HIGH);
     TX_mode=1;
     if (debug_level>1) Serial1.println("TRANSMIT");
     
     while (((time_elapsed<100)) & (digitalRead(LNABOX_FEEDBACK)==HIGH) )    //repeat untill time elapsed < 100ms and feedbak received
     {
         time_elapsed=millis()-timer_start;
     }
      if (time_elapsed<100)             //if we ave wated <100ms for feedback from LNA box
      {
        tx_on=1;
        delay(20);                       //wait additional 20ms to enable transmision <------------------------------------------------------
        digitalWrite(PTT_INH, HIGH);    // enable transmit

      }
      else   //if feedback from LNA BOX not received in time
      {
        err_code=(err_code | B00000100);     // set error code
        digitalWrite(PTT_INH, LOW);          // do not allow to start TX
        tx_on=0;                              
      }
      if (debug_level>2)
        {
         Serial1.print(timer_start);
         Serial1.print(" ");
         Serial1.print(millis());
         Serial1.print(" ");
         Serial1.println(time_elapsed);
        }

     
  }
  else 
  //if (RX_enable)               // we actually do not need this here
  {
     set_att(global_att);        //return to previous att
     disp_qrg(global_qrg);
     TX_mode=0;
     //digitalWrite(FLTR_BPS, LOW);
     lcd.setCursor(14, 0);
     lcd.print("RX");
     digitalWrite(LED_Y,LOW);
     if (debug_level>1) Serial1.println("RECEIVE ");
     digitalWrite(PTT_INH, LOW);
    // tx_on=0;
  }

 
 
  send_status();  
  error_handler();
}

void Cable_interrupt() {                    //this activates when tere is an change from radio (cable connected or radio switched on/off)
  err_code=(err_code & B11111110);         // reesets code for this procedure
  if (digitalRead(CABLE_CONNECTED)==LOW)
   {
     RX_enable=0;
     err_code=(err_code | B00000001);
     //digitalWrite(PTT_FORCE,HIGH);                               //forces TX path to actiate - we ave to assume, that no LNA box is connected.
   }
   else
   {
     RX_enable=1;
   }
 error_handler();
}

void reset_holding(){   //sets all stepper driver pins for reducing power consumption and heat generation

  digitalWrite(motor_pin_A,LOW);
  digitalWrite(motor_pin_B,LOW);
  digitalWrite(motor_pin_C,LOW);
  digitalWrite(motor_pin_D,LOW);
}

void disp_qrg(long frq){
  if (bypass_on==0) {
    lcd.setCursor(1, 0);
    lcd.print(frq);
    lcd.setCursor(0, 0); 
    lcd.print(int(frq/1000));
    lcd.print(".");
    lcd.setCursor(7, 0);
    lcd.print("MHz");
  }
  if (bypass_on==1) {
   lcd.setCursor(0, 0);       //update info on LCD
   lcd.print(" -BYPASS- ");
  }

}

void error_handler(){
  if (err_code>0)
  {
    digitalWrite(LED_R, HIGH);
    lcd.setCursor(9, 1);
    lcd.print("ERROR");
    lcd.print(err_code);
    Serial1.print("ERROR ");
    
    if (err_code & B00000001){
      Serial1.println("Radio NOT connected");
    }
    if (err_code & B00000010){
      Serial1.println("Problem with filter");
    }
    if (err_code & B00000100){
      Serial1.println("No response from LNA BOX");
    }

  }
  else
  {
    digitalWrite(LED_R, LOW);
    lcd.setCursor(9, 1);
    lcd.print("       ");
  }
  //here we should take care about displaying all rerors
}

void set_att(byte att){ //sets the defined pins for digital (binary) output
    digitalWrite(ATT_V6, HIGH && (att & B00100000));  //MSB
    digitalWrite(ATT_V5, HIGH && (att & B00010000));
    digitalWrite(ATT_V4, HIGH && (att & B00001000));
    digitalWrite(ATT_V3, HIGH && (att & B00000100));
    digitalWrite(ATT_V2, HIGH && (att & B00000010));
    digitalWrite(ATT_V1, HIGH && (att & B00000001));  //LSB
}

void disp_att(byte att) {   //displays att level on LCD (in steps of 0.5dB)
    lcd.setCursor(0, 1);
    lcd.print("ATT ");
    lcd.setCursor(4, 1);
    lcd.print("-");
    lcd.print(int(att/2));
    lcd.print(".");
    if ((att%2)>0)
      {lcd.print("5");}
    else
      {lcd.print("0");}  
}

void reset_step(){  // retracts filter core untill pass limitt switch, then moves it back, just past it and resets count
long steps_made=0;
err_code=(err_code & B11111101);                                //resets error code for filter
  while ((digitalRead(filter_limit_pin)==LOW) and (filter_ok)){
     myStepper.step(1);
     delay(5);
     steps_made++;
      if (debug_level>2) Serial1.print("-");
      IWatchdog.reload();             //restet watchdog
     if (steps_made>2100) 
      {
        filter_ok=0;
        err_code=(err_code | B00000010);
      }
  }
  steps_made=0;
   while ((digitalRead(filter_limit_pin)==HIGH) and (filter_ok)){
     myStepper.step(-1);
     IWatchdog.reload();             //restet watchdog
     delay(50);
     steps_made++;
     if (steps_made>20)
     {
        filter_ok=0;
        err_code=(err_code | B00000010);
      }
   }

  stepCount=0;      //resets stepper count after reset procedure
  global_qrg=initial_qrg;
  disp_qrg(global_qrg);    //show approx freq on LCD
  
  reset_holding();  //resets holding power to reduce current consumption and heat generation
  error_handler();
  send_status();
}

void bypass_filter(boolean on){

  //digitalWrite(FLTR_BPS, !on);  //set pypass pin to appropriate state
  if (on==1) {
    
    digitalWrite(FLTR_BPS,LOW);
    disp_qrg(global_qrg);               //this will display bypass as well
    bypass_on=1;
  }
  else {
    
    //lcd.setCursor(0, 0);
    digitalWrite(FLTR_BPS,HIGH);
    disp_qrg(global_qrg);
    bypass_on=0;
  }
  send_status();
  
}

void menuDisplay() 
{

  if ((menu_timeout==menu_timeout_max) | (menu_timeout<(menu_timeout_max-500)))
  {
    menu_timeout=menu_timeout_max-1;
    menu_item++;
    if (menu_item==4) menu_item=1;
    lcd.setCursor(0, 1);       //update info on LCD
    if (menu_item==1) lcd.print("Bypass         ");
    if (menu_item==2) lcd.print("TX mode        ");
    if (menu_item==3) lcd.print("Reset filter   ");
    
   
  }
 
}

void menuExe(){

byte tx_line_status;

  if (menu_timeout<menu_timeout_max){
    if (menu_item==1) bypass_filter(!bypass_on);
    if (menu_item==2) { tx_line_status=digitalRead(PTT_FORCE); digitalWrite(PTT_FORCE,!tx_line_status); }
    if (menu_item==3) reset_step();
    menu_item=0;
    menu_timeout=menu_timeout_max;
    lcd.setCursor(0, 1);       //update info on LCD
    lcd.print("               ");
    disp_att(global_att);
    disp_qrg(global_qrg);

  }
}


void send_status(){            
                        //Status : "STST, Approx freq in kHz, number of steps of tunable filter, bypass on/off, attenator value (not used), RX enable=1 TX mode=0, TX in transmit mode, error code"

  NMEA_String="STST,";
  NMEA_String+=global_qrg;
  NMEA_String+=",";
  NMEA_String+=stepCount;
  NMEA_String+=",";
  NMEA_String+=bypass_on;
  NMEA_String+=",";
  NMEA_String+=global_att;
  NMEA_String+=","; 
  NMEA_String+=TX_mode; 
  NMEA_String+=","; 
  NMEA_String+=tx_on;
  NMEA_String+=","; 
  NMEA_String+=err_code;


  Serial1.println(NMEA_String);
}

void tune_filter(int steps){
  if (bypass_on==0)
  {
   if ((stepCount+steps)<0) steps=0;                      //if we are within limits
   if (stepCount+steps>1000) steps=0;
   keyb_disable(); 
   for (int a=0; a<abs(steps); a++){                           //move filter required number of steps
    if (steps>0) {
      myStepper.step(-1);
      stepCount++;
     }
    else {
      myStepper.step(+1);
      stepCount--;
    }
    delay(5);
    IWatchdog.reload();
    reset_holding();
    }
   keyb_enable();
   global_qrg=initial_qrg-int((stepCount*1000)/steps_per_MHz);
   disp_qrg(global_qrg);    //show approx freq on LCD
   if (debug_level>2) Serial1.print("  StepCount ");
   if (debug_level>2) Serial1.println(stepCount);  
   send_status();
   steps=0;
  }

}

void loop() {
  static uint32_t count;
  static uint32_t prevCount;
  static byte prev_att=1;
  byte step_no=0;

  if (step_inc !=0) {                                         //change of encoder status
    keyb_disable();                                           //this is not working I think
   if (debug_level>2) Serial1.print("step_inc ");
   if (debug_level>2) Serial1.print(step_inc);  
    tune_filter((-1)*step_inc);                              // step UP truns freuency down, thus -1*step. 
    step_inc=0;
  } 
  
  if (prev_att!=global_att){           //if we have change in att. seting
      set_att(global_att);
      disp_att(global_att);
      prev_att=global_att;
  }
   
  if (menu_timeout==0){
     menu_timeout=menu_timeout_max;
     menu_item=0;
     lcd.setCursor(0, 1);       //update info on LCD
     lcd.print("               ");
     disp_att(global_att);

   }
  
  if (Serial1.available() > 0) {
                // read the incoming byte:

                //Commands so far...
                //STr - reset filter - go back to limit switch
                //STT - force on TX 
                //STR - force off tx
                //STB0 - switch off bypass
                //STB1 - switch on bypass
                //ST+[number] - adance filter [number] of steps
                //ST-[number] - retard filter [number] of steps
                
                
                comm = comm+char(Serial1.read());
        
                letter=letter+1;
                
                // Serial1.println(comm[letter-1]);
                if (comm[letter-1]==10) {    //end of line
                 if ((comm[0]=='S') && (comm[1]=='T')) {
                   sign_l=comm[2];
                   
                   if (sign_l=='r') {
                    reset_step();
                    if (debug_level>1) Serial1.println("reset");
                   }
                   else

                   if (sign_l=='T') {      //Transmit command - force PTT signal (FORCES diregarding external sources)
                    digitalWrite(PTT_FORCE,HIGH);
                   }
                   else

                   if (sign_l=='R') {      //Receive command - release PTT signal (still controlled by external source)
                    digitalWrite(PTT_FORCE,LOW);
                   }
                   else

                   if (sign_l=='B') {
                    if (comm[3]=='0') { 
                      bypass_filter(0); }
                    if (comm[3]=='1') { 
                      bypass_filter(1); }
                   }

                   else
                   if (sign_l=='?') {
                     send_status();
                   }

                   else

                  if ((sign_l=='+') | (sign_l=='-'))
                   {
                      step_l=comm.substring(3);
                      step_inc1=step_l.toInt();
                     if ((sign_l=='-') && ((stepCount-step_inc1)<0)) {
                        step_inc1=stepCount;
                        step_l="min ";
                      }
                      if ((sign_l=='+') && ((stepCount+step_inc1)>1000)) {
                         step_inc1=1000-stepCount;
                         step_l="max ";
                      }
                      

                     if (sign_l=='-')  {step_inc1=(-1)*step_inc1;}

                     tune_filter(step_inc1);
                      
                      }                    
                   
                 
                   }
                   else{
                     Serial1.println("hmmmm?");
                  
                     }
                   comm="";
                  letter=0;
                 }
  }
  // step one step:
  
IWatchdog.reload();             //restet watchdog

}

  #ifdef STM32DUINO_CORE                     //checks encoder every 1ms
  void HAL_SYSTICK_Callback()
   {
     if (kbd_enable) encoder1_read();
   }
  #endif
  

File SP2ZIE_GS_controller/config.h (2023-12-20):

#ifndef CONFIG_H
#define CONFIG_H

//Serial 1 ports are:
// PB9 - TX
// PB10 - RX

// Stepper motor pins
#define motor_pin_D PB10
#define motor_pin_C PB1
#define motor_pin_B PA15
#define motor_pin_A PB3

#define filter_limit_pin PA7

#define CABLE_CONNECTED PB4

#define LED_Y PB5
#define LED_R PB8

#define KEY_L PB13
#define KEY_R PB12

#define ENC_PRESS PA8
#define ENC_CLK PB15
#define ENC_DATA PB14



#define VOLT_INP PA1

// Attenuator pins
#define ATT_V1 PB9    //LSB
#define ATT_V2 PA2
#define ATT_V3 PA3
#define ATT_V4 PA4
#define ATT_V5 PA5
#define ATT_V6 PA6    //MSB

//filter bypass pin
#define FLTR_BPS PB11

//transmit pin (should switch off power to LNA and force max attenaution
#define PTT_IN PB0

#define LNA_BOX_SW PC13       // TX/RX switch feedback from LNA box
#define PTT_FORCE PA0         // Force TX by microcontroler
#define PTT_OUT PC14          // PTT OUT to radio - controlled by microcontroller
#define PTT_INH PC15          // When high (high resistance) no TX is possible (yaesu)
#define LNABOX_FEEDBACK PC13  // Feedback from LNA BOX

#define KEY1 PB12
#define KEY2 PB13
#define KEY3 PB14
#define ENC_PIN1 PB15
#define ENC_PIN2 PB8



#endif // CONFIG_H

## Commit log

2023-12-20 First release - very much work in progress...
    First semi-functional release of SP2ZIE GS controller.
    Bluepill arduino code
2023-12-20 Kicad schematic of GS controller board
    Quick and dirt - PCB not updated with latest changes. Design changes reuired - LCD based on i2c now, some pins (former LCD) used for other functions (cable conn det, etc). PA1 pin reassigned for anal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
    [distr_filter.kicad_pcb, distr_filter.kicad_sch, distr_filter.sch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]
2023-12-27 TX / RX switch controller for LNA box
    Initial commit
    [lna_switch.kicad_pcb, lna_switch.sch, lna_switch_2.kicad_pcb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]
2024-01-03 Updated and proed changes. Mostly about bypass action
    Checked on working device.
2024-07-04 Block schematic of SP2ZIE Schooner ground station
2024-07-04 GS antenna system
2024-07-04 LNA box block schematic
2024-07-05 Block schematic of ground station
2024-07-05 Block diagram of ground station
